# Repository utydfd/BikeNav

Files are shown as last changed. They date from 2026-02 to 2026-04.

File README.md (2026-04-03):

# BikeNav
An GPS navigation(originally intended for biking) with an E-ink screen, ESP32-S3 MCU and an SD card.
This repository contains code for the Arduino project and an Android app, as well as a PCB designed in KiCad and a case designed in Fusion 360.

## Map format
It uses standard raster 256x256px map tiles, right now from OSM, but can be changed to others.
The tiles are saved on the SD card in a ```ZOOM_LEVEL/X/Y.tile``` folder structure as 1 bit bitmap images.

## Data flow

Either import a GPX track or plan right inside the app(right now using project OSRM API), it downloads the required map tiles and saves them.

I can pick a trip from the main screen and send it over to the ESP via BLE, first the GPX is sent and then the tiles. They are converted from PNG to bitmap, compressed using RLE for faster transfers. The ESP is saving them to the SD card as they come. It’s also appending an index of tiles, which is sent from the ESP to the app, so that only the missing tiles are sent.

## ESPs software

The home screen contains smartphone like icons to "apps". The main one is obviously the map, which by default shows the current location. Pressing options brings up list of saved trips, clicking on it shows the preview and i can also start the navigation.

When navigating, the map rotates based on the upcoming GPX track; it shows the next turn distance and turn arrow(just calculated based on the angle of the turn). There are also screens for the progress and elevation graph. The GPX is loaded into PSRAM *(512kb allocated)* and PSRAM is also used for caching the map tiles *(~6MB allocated)*.

Other apps include the speedometer, phone(which has music controls along with battery %), weather(phone fetches from an API the forecast and also rain radar images), tracker(for recording GPX tracks), info(was used for debugging, has GPS, SD and battery statuses) and also mines and snake games. Those are not ideal but playable on the E-ink.

## Hardware

Its on a custom PCB, a standard 2 layer one. There are 2 regulators, one powering the ESP and other parts and the other solely for powering the front light - it has the EN pin connected to a GPIO so its controlled in software. The GPS module is connected via UART and also has an EN pin controllable. Micro SD card and the display are connected via SPI to the ESP. There is a TP4056 chip for charging, without the LEDs - its connected to the ESP so it can know the charging status.

For control, there is a rotary encoder(with a button) and 4 more buttons. The battery voltage is monitored with the ESP.

## BOM
- [Display](https://www.aliexpress.com/item/1005005183232092.html)
- [GP-02 GPS module](https://www.aliexpress.com/item/1005008117586848.html)
- [ESP32-S3 wroom module](https://www.aliexpress.com/item/1005004639132852.html)
- [SPX3819M5 LDO 3V3 regulator](https://www.aliexpress.com/item/1005004418830711.html)
- [2.2uF ceramic capacitors](https://www.aliexpress.com/item/1005002769519482.html)
- [15mm rotary endoder](https://www.aliexpress.com/item/1631706397.html)
- [USB-C breakout module](https://www.aliexpress.com/item/1005008296556115.html)

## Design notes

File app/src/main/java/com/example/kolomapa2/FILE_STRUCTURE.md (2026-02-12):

# KoloMapa2 - File Structure

Android companion app for ESP32S3 bicycle navigation device. This app downloads GPX routes, processes map tiles, and sends data to the ESP device via Bluetooth LE.

## Root Level

### `MainActivity.kt`
Main Android activity entry point. Handles incoming GPX file intents from file managers or share actions. Sets up Compose UI and delegates to MainScreen.

### `MainViewModel.kt`
Central ViewModel coordinating all app logic. Manages:
- Trip import/deletion
- Map tile downloading with progress tracking
- BLE connection to ESP32S3
- Data transfer (trips and tiles) to device
- UI state (loading, errors, storage stats)

## Models (`models/`)

### `Trip.kt`
Simple data class combining trip metadata and GPX content string.

### `TripMetadata.kt`
Serializable trip information including:
- Name, distance, elevation gain/loss
- Point count and bounding box
- Route description with origin/destination parsing
- Timestamp

## UI (`ui/`)

### `MainScreen.kt`
Main Compose UI with:
- Trip list display with cards
- BLE connection status indicator
- Import GPX file picker
- Trip details dialog
- Storage statistics
- Transfer progress indicators
- Permission requests (Bluetooth, location, storage)

### Theme files (`ui/theme/`)
- `Color.kt` - Material Design color palette
- `Theme.kt` - App theme configuration
- `Type.kt` - Typography definitions

## Utils (`utils/`)

### `BleManager.kt`
Bluetooth LE communication with ESP32S3:
- Device scanning and connection management
- Custom service UUID: 12345678-1234-1234-1234-123456789abc
- Tile transfer with RLE compression (16KB ESP limit)
- Tile inventory sync to skip tiles already on device
- Trip data transfer (GPX + metadata JSON)
- MTU negotiation (517 bytes) and chunked transfers (500 byte chunks)
- Flow control with write completion flags

### `GpxParser.kt`
Parses GPX XML files to extract:
- Track points (lat/lon/elevation)
- Trip names from metadata and track elements
- Route descriptions with origin→destination parsing
- Statistics: distance (Haversine formula), elevation changes
- Bounding box calculation

### `RleCompression.kt`
Run-Length Encoding compression for map tiles:
- Optimized for 1-bit bitmaps with large uniform areas
- Format: [count][value] pairs with 2-byte size header
- Compression ratio calculation
- Encode/decode with validation

### `StorageManager.kt`
File system operations in external storage (`/KoloMapa2/`):
- Trips: Save/load GPX files and metadata JSON
- Map tiles: Store preprocessed 1-bit bitmaps (zoom/x/y.bin)
- Storage statistics (total size, counts)
- Tile existence checking

### `TileDownloader.kt`
Downloads map tiles from OpenStreetMap tile servers:
- Uses keyless public raster tiles (`z/x/y.png`)
- Downloads zoom levels 9-18 with 2-tile padding
- Caching: skips already downloaded tiles
- Automatic preprocessing to 1-bit format
- Progress callbacks

### `TilePreprocessor.kt`
Converts PNG map tiles to 1-bit bitmaps (matches ESP32S3 processing):
- Floyd-Steinberg dithering with error diffusion
- Image processing: gamma correction (2.50), contrast (1.3), threshold (128)
- Output: 8KB per tile (256x256 pixels, 8 pixels per byte)
- Tile coordinate calculation (lat/lon → tile x/y)
- MUST match Arduino preprocessing exactly for consistency

## Data Flow

1. User imports GPX → `GpxParser` extracts route → `StorageManager` saves
2. `TileDownloader` fetches tiles for route bounding box
3. `TilePreprocessor` converts PNG → 1-bit bitmap → `StorageManager` saves
4. User sends to ESP → `BleManager` requests tile inventory, transfers trip + missing tiles via BLE
5. ESP32S3 receives and displays on e-paper screen

## Key Design Decisions

- External storage for persistence across reinstalls
- Exact preprocessing match with Arduino for consistent map rendering
- RLE compression for efficient BLE transfer (ESP has 16KB tile limit)
- Chunked transfers with flow control for reliability
- Offline-first: all data cached locally before transfer

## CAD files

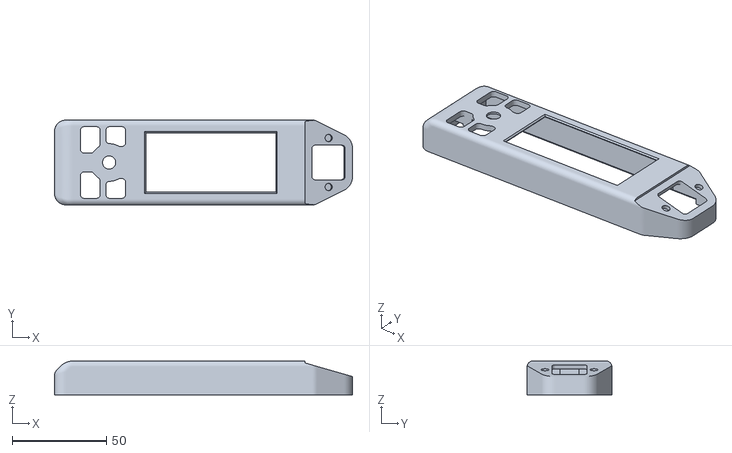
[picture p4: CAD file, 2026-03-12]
Case/top.stl
158.1 x 45.0 x 18.0

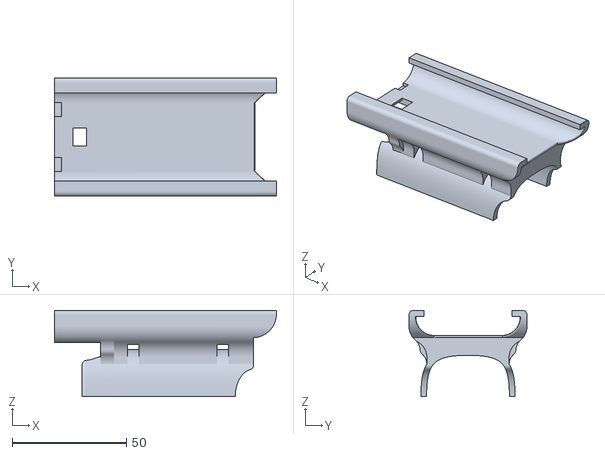
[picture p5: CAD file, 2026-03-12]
Case/mount.stl
97.0 x 51.6 x 37.8

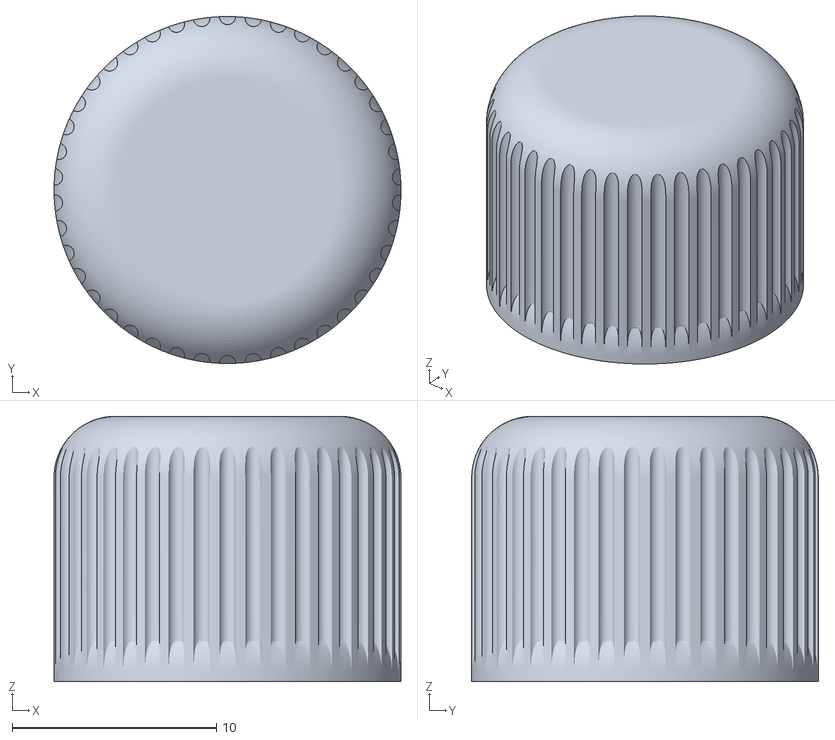
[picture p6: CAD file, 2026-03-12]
Case/knob.stl
17.0 x 17.0 x 13.0

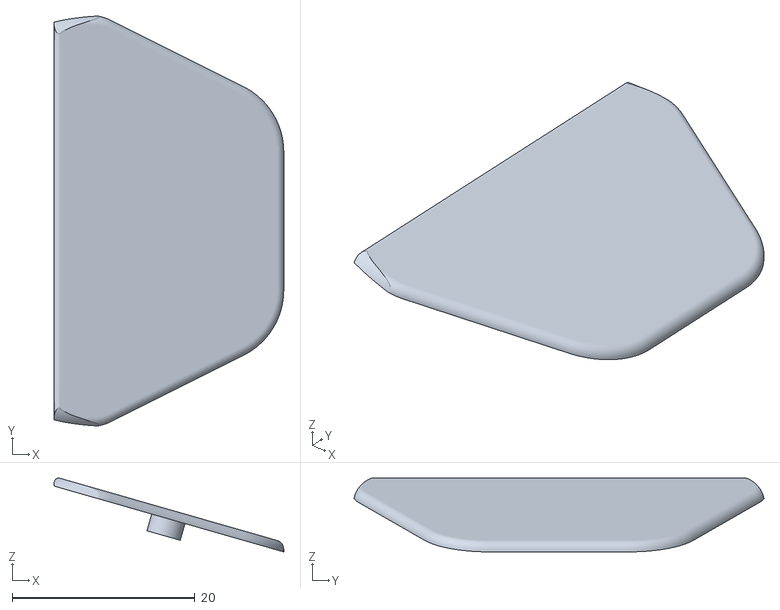
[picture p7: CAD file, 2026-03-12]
Case/cover.stl
25.1 x 44.9 x 8.08

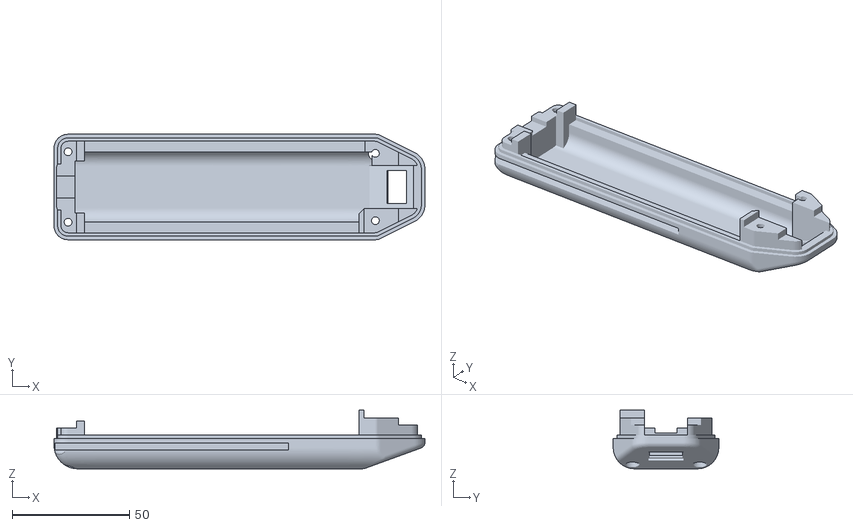
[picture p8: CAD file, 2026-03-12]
Case/bottom.stl
158.1 x 45.0 x 25.0

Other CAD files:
Case/KoloMapa2.f3d

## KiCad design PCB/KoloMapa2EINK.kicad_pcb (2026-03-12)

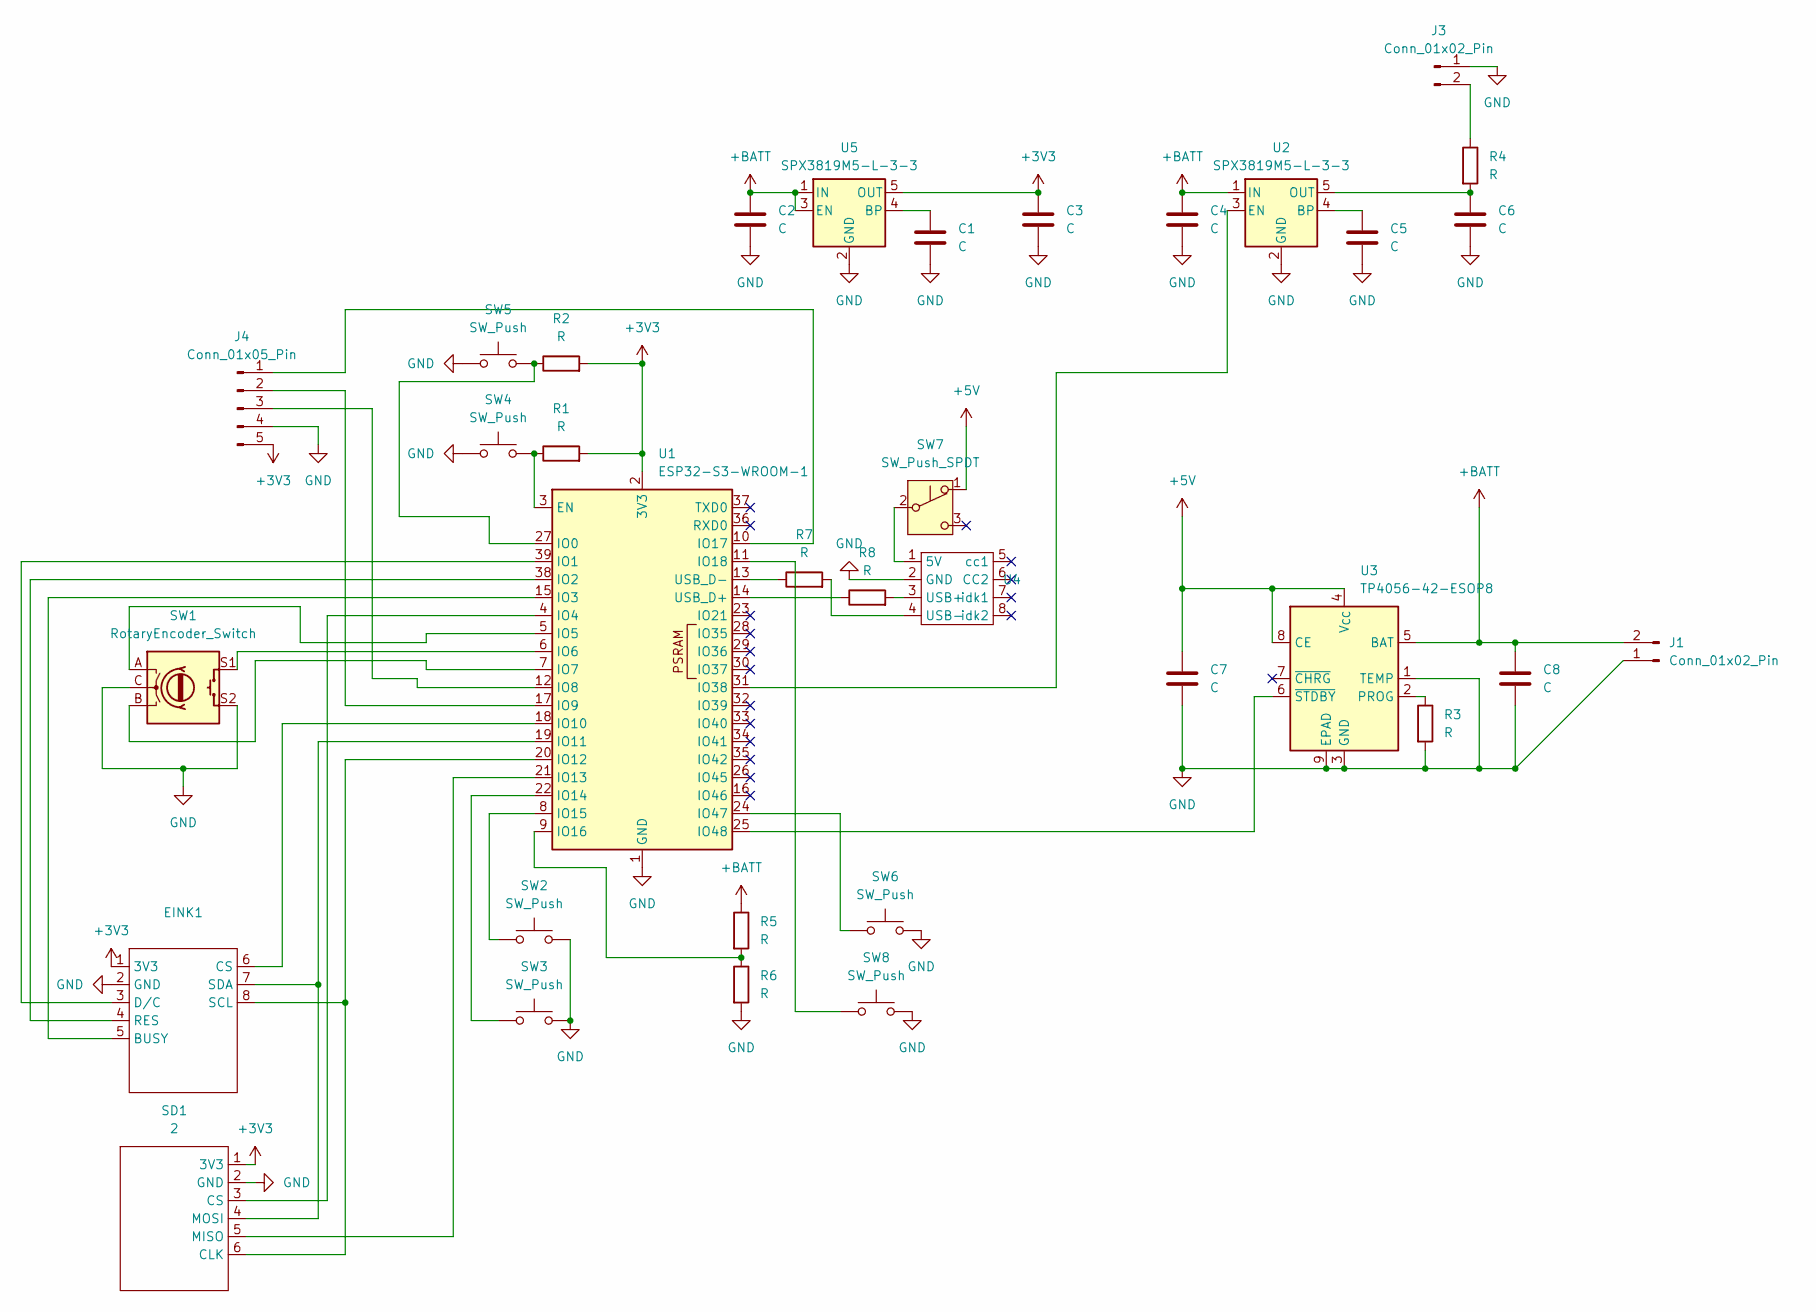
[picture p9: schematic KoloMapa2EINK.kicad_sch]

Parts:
C1, C2, C3, C4, C5, C6: C; C_1206_3216Metric_Pad1.33x1.80mm_HandSolder
C7: C; C_0402_1005Metric
C8: C; C_0504_1310Metric
EINK1: EINK
J1, J3: Conn_01x02_Pin; PinHeader_1x02_P2.54mm_Vertical
J4: Conn_01x05_Pin; PinHeader_1x05_P2.00mm_Vertical
R1, R2, R4, R5, R6: R; R_Axial_DIN0207_L6.3mm_D2.5mm_P10.16mm_Horizontal
R3: R; R_0402_1005Metric
R7, R8: R; R_Axial_DIN0207_L6.3mm_D2.5mm_P2.54mm_Vertical
SD1: 2; SD
SW1: RotaryEncoder_Switch; RotaryEncoder_Alps_EC11E-Switch_Vertical_H20mm
SW2, SW3, SW4, SW5, SW6, SW8: SW_Push; SW_PUSH_6mm
SW7: SW_Push_SPDT; SW_Slide_SPDT_Straight_CK_OS102011MS2Q
U1: ESP32-S3-WROOM-1
U2, U5: SPX3819M5-L-3-3; SOT-23-5
U3: TP4056-42-ESOP8; SOIC-8-1EP_3.9x4.9mm_P1.27mm_EP2.41x3.3mm_ThermalVias
U4: Untitled

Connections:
+3V3: C3.1, EINK1.1 (3V3), J4.5, R1.2, R2.2, SD1.1 (3V3), U1.2 (3V3), U5.5 (OUT)
+5V: C7.1, SW7.1 (A), U3.4 (V_{CC}), U3.8 (CE)
+BATT: C2.1, C4.1, C8.1, J1.2, R5.1, U2.1 (IN), U3.5 (BAT), U5.1 (IN), U5.3 (EN)
GND: C1.2, C2.2, C3.2, C4.2, C5.2, C6.2, C7.2, C8.2, EINK1.2 (GND), J1.1, J3.1, J4.4, R3.2, R6.2, SD1.2 (GND), SW1.C, SW1.S2, SW2.2, SW3.2, SW4.1, SW5.1, SW6.2, SW8.2, U1.1 (GND), U1.40 (GND), U1.41 (GND), U2.2 (GND), U3.1 (TEMP), U3.3 (GND), U3.9 (EPAD), U4.2 (GND), U5.2 (GND)
unnamed: EINK1.5 (BUSY), U1.15 (IO3)
unnamed: EINK1.6 (CS), U1.18 (IO10)
unnamed: EINK1.3 (D/C), U1.39 (IO1)
unnamed: EINK1.4 (RES), U1.38 (IO2)
unnamed: EINK1.8 (SCL), SD1.6 (CLK), U1.20 (IO12)
unnamed: EINK1.7 (SDA), SD1.4 (MOSI), U1.19 (IO11)
unnamed: J3.2, R4.1
unnamed: J4.1, U1.10 (IO17)
unnamed: J4.2, U1.17 (IO9)
unnamed: J4.3, U1.12 (IO8)
unnamed: SD1.3 (CS), U1.4 (IO4)
unnamed: SD1.5 (MISO), U1.21 (IO13)
unnamed: SW7.2 (B), U4.1 (5V)
unnamed: R1.1, SW4.2, U1.3 (EN)
unnamed: R2.1, SW5.2, U1.27 (IO0)
unnamed: SW1.A, U1.5 (IO5)
unnamed: SW1.S1, U1.6 (IO6)
unnamed: SW1.B, U1.7 (IO7)
unnamed: SW3.1, U1.22 (IO14)
unnamed: SW2.1, U1.8 (IO15)
unnamed: R5.2, R6.1, U1.9 (IO16)
unnamed: SW8.1, U1.11 (IO18)
unnamed: U1.31 (IO38), U2.3 (EN)
unnamed: SW6.1, U1.24 (IO47)
unnamed: U1.25 (IO48), U3.6 (~STDBY)
unnamed: R8.1, U1.14 (USB_D+)
unnamed: R7.1, U1.13 (USB_D-)
unnamed: C5.1, U2.4 (BP)
unnamed: C6.1, R4.2, U2.5 (OUT)
unnamed: R3.1, U3.2 (PROG)
unnamed: R8.2, U4.3 (USB+)
unnamed: R7.2, U4.4 (USB-)
unnamed: C1.1, U5.4 (BP)

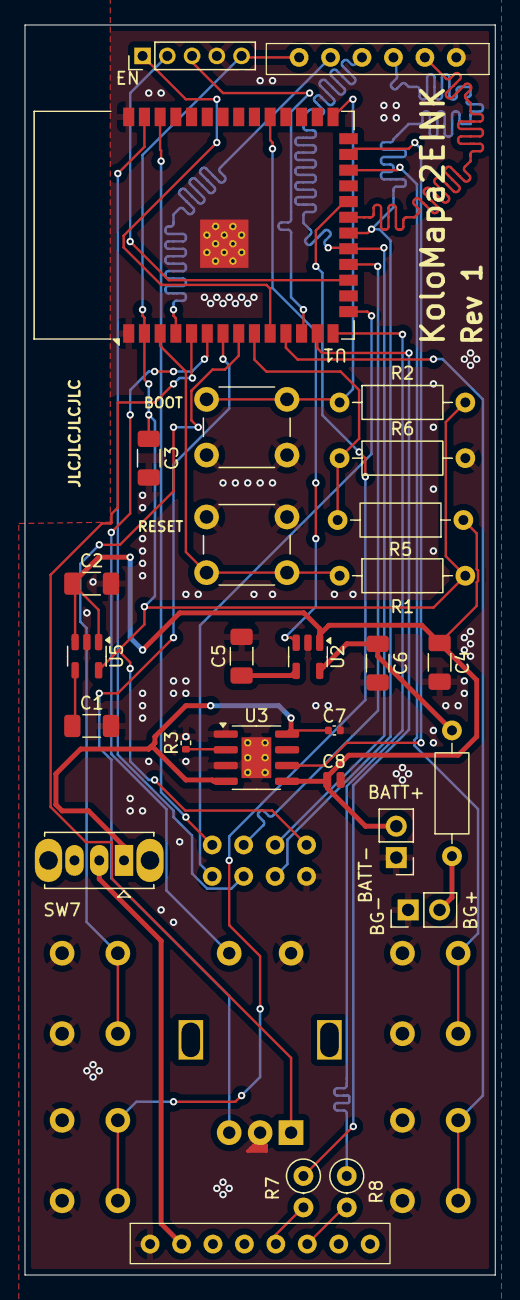
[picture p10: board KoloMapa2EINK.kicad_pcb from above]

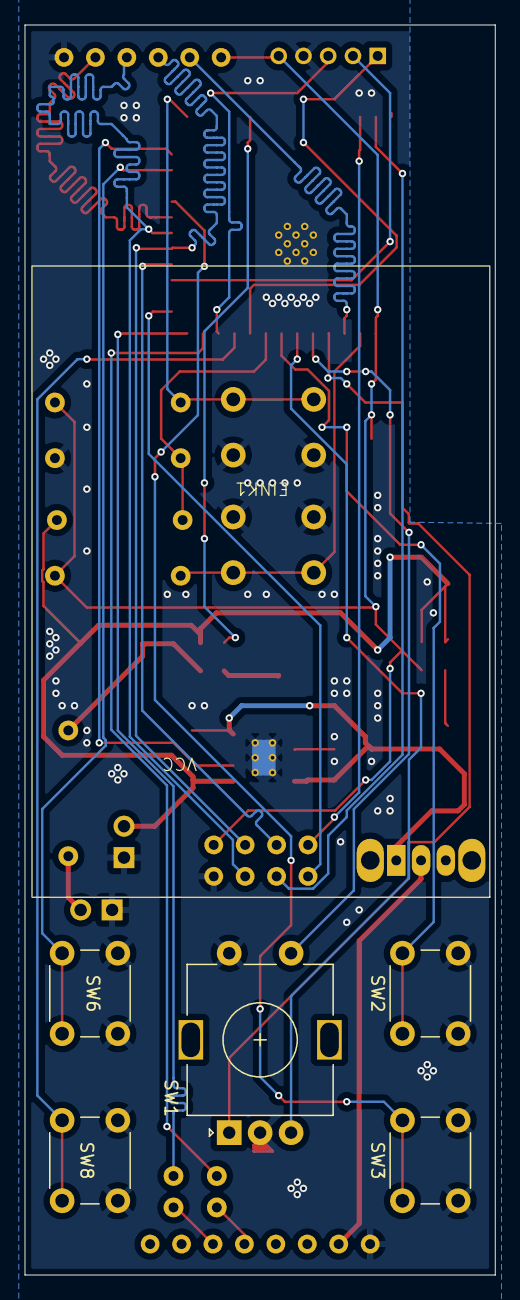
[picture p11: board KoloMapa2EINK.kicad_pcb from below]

Board: 2 copper layers, 38.0 x 101.0 mm, 34 parts (6 on the bottom side), 37 nets.

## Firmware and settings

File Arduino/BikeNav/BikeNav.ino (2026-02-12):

#include <GxEPD2_BW.h>
#include <U8g2_for_Adafruit_GFX.h>
#include <HardwareSerial.h>
#include <TinyGPS++.h>
#include <SPI.h>
#include <SD.h>
#include <time.h>
#include <sys/time.h>

// --- PAGE MANAGEMENT ENUM (must be before page includes) ---
enum PageType {
  PAGE_MAIN_MENU,
  PAGE_MAP,
  PAGE_SPEEDOMETER,
  PAGE_PHONE_APP,
  PAGE_WEATHER,
  PAGE_GAMES,
  PAGE_INFO,
  PAGE_SHUTDOWN,
  PAGE_SETTINGS,
  PAGE_TRACKER,
  PAGE_RECORDING,
  PAGE_RECORDING_OPTIONS,
  PAGE_WEATHER_OPTIONS,
  PAGE_SNAKE
};

// Forward declaration of navigateToPage (needed by page headers)
void navigateToPage(PageType page);

// Include all page headers
#include "timezone.h"
#include "bitmaps.h"
#include "tile_cache.h"
#include "ble_handler.h"
#include "battery_manager.h"
#include "notification_system.h"
#include "power_manager.h"
#include "status_bar.h"
#include "page_main_menu.h"
#include "page_map.h"
#include "page_speedometer.h"
#include "page_phone_app.h"
#include "page_weather.h"
#include "page_radar.h"
#include "page_weather_options.h"
#include "page_games.h"
#include "page_snake.h"
#include "page_info.h"
#include "page_settings.h"
#include "page_tracker.h"
#include "page_recording.h"
#include "page_recording_options.h"

// --- E-PAPER DISPLAY CONFIGURATION ---
#define EPD_CS_PIN 10
#define EPD_DC_PIN 1
#define EPD_RES_PIN 2
#define EPD_BUSY_PIN 3

// --- SD CARD CONFIGURATION ---
#define SD_CS_PIN 4

GxEPD2_BW<GxEPD2_290_BS, GxEPD2_290_BS::HEIGHT> display(GxEPD2_290_BS(EPD_CS_PIN, EPD_DC_PIN, EPD_RES_PIN, EPD_BUSY_PIN));
U8G2_FOR_ADAFRUIT_GFX u8g2_display;

// --- BATTERY MANAGER ---
BatteryManager batteryManager;

// --- GPS CONFIGURATION ---
#define RX1_PIN 8
#define TX1_PIN 9
HardwareSerial GPS_Serial(1);
TinyGPSPlus gps;

// --- TIMEZONE CONFIGURATION ---
// GPS returns UTC time. Automatic DST adjustment for Czech Republic.
// Winter (CET): UTC+1, Summer (CEST): UTC+2
// DST period: Last Sunday of March 2:00 AM to Last Sunday of October 3:00 AM

// Helper function to find the last Sunday of a given month and year
int getLastSundayOfMonth(int year, int month) {
  // Days in month
  const int daysInMonth[] = {31, 28, 31, 30, 31, 30, 31, 31, 30, 31, 30, 31};
  bool isLeapYear = (year % 4 == 0 && year % 100 != 0) || (year % 400 == 0);
  int lastDay = daysInMonth[month - 1];
  if (month == 2 && isLeapYear) {
    lastDay = 29;
  }

  // Calculate day of week for the last day of the month
  // Using Zeller's algorithm
  int q = lastDay;
  int m = month;
  int y = year;

  // Zeller's algorithm: for January and February, count them as months 13 and 14 of the previous year
  if (m < 3) {
    m += 12;
    y--;
  }

  int h = (q + (13 * (m + 1)) / 5 + y + y / 4 - y / 100 + y / 400) % 7;
  // h: 0=Saturday, 1=Sunday, 2=Monday, ..., 6=Friday

  // Find how many days to go back to reach Sunday (h=1)
  int daysBack = (h + 6) % 7;  // Days to go back from last day to last Sunday

  return lastDay - daysBack;
}

// Check if DST is active for Czech Republic
// DST: Last Sunday of March 2:00 UTC to Last Sunday of October 3:00 UTC
bool isDSTActive(int year, int month, int day, int hour) {
  int marchLastSunday = getLastSundayOfMonth(year, 3);
  int octoberLastSunday = getLastSundayOfMonth(year, 10);

  // Before March or after October -> winter time
  if (month < 3 || month > 10) {
    return false;
  }

  // April to September -> summer time
  if (month > 3 && month < 10) {
    return true;
  }

  // March: check if we're past the last Sunday at 2:00 AM
  if (month == 3) {
    if (day < marchLastSunday) {
      return false;
    } else if (day == marchLastSunday) {
      return hour >= 2;  // DST starts at 2:00 AM UTC
    } else {
      return true;
    }
  }

  // October: check if we're before the last Sunday at 3:00 AM
  if (month == 10) {
    if (day < octoberLastSunday) {
      return true;
    } else if (day == octoberLastSunday) {
      return hour < 3;  // DST ends at 3:00 AM UTC
    } else {
      return false;
    }
  }

  return false;
}

// Get timezone offset based on DST status
int getTimezoneOffset(int year, int month, int day, int hour) {
  return isDSTActive(year, month, day, hour) ? 2 : 1;  // +2 for summer, +1 for winter
}

// Convert GPS UTC time to local time with automatic DST adjustment
LocalTime getLocalTime() {
  LocalTime localTime;

  if (!gps.time.isValid() || !gps.date.isValid()) {
    // Return zeros if GPS time not available
    localTime.hour = 0;
    localTime.minute = 0;
    localTime.second = 0;
    localTime.day = 0;
    localTime.month = 0;
    localTime.year = 0;
    return localTime;
  }

  // Start with GPS UTC time
  localTime.hour = gps.time.hour();
  localTime.minute = gps.time.minute();
  localTime.second = gps.time.second();
  localTime.day = gps.date.day();
  localTime.month = gps.date.month();
  localTime.year = gps.date.year();

  // Calculate timezone offset based on UTC date/time for automatic DST
  int timezoneOffset = getTimezoneOffset(localTime.year, localTime.month, localTime.day, localTime.hour);
  localTime.hour += timezoneOffset;

  // Handle hour overflow (next day)
  if (localTime.hour >= 24) {
    localTime.hour -= 24;
    localTime.day++;

    // Days in month lookup (non-leap year, February handled separately)
    const int daysInMonth[] = {31, 28, 31, 30, 31, 30, 31, 31, 30, 31, 30, 31};

    // Check for leap year for February
    bool isLeapYear = (localTime.year % 4 == 0 && localTime.year % 100 != 0) || (localTime.year % 400 == 0);
    int maxDays = daysInMonth[localTime.month - 1];
    if (localTime.month == 2 && isLeapYear) {
      maxDays = 29;
    }

    // Handle day overflow (next month)
    if (localTime.day > maxDays) {
      localTime.day = 1;
      localTime.month++;

      // Handle month overflow (next year)
      if (localTime.month > 12) {
        localTime.month = 1;
        localTime.year++;
      }
    }
  }
  // Handle hour underflow (previous day)
  else if (localTime.hour < 0) {
    localTime.hour += 24;
    localTime.day--;

    // Handle day underflow (previous month)
    if (localTime.day < 1) {
      localTime.month--;

      // Handle month underflow (previous year)
      if (localTime.month < 1) {
        localTime.month = 12;
        localTime.year--;
      }

      // Set to last day of previous month
      const int daysInMonth[] = {31, 28, 31, 30, 31, 30, 31, 31, 30, 31, 30, 31};
      bool isLeapYear = (localTime.year % 4 == 0 && localTime.year % 100 != 0) || (localTime.year % 400 == 0);
      localTime.day = daysInMonth[localTime.month - 1];
      if (localTime.month == 2 && isLeapYear) {
        localTime.day = 29;
      }
    }
  }

  return localTime;
}

// --- INPUT PINS ---
#define CLK_PIN 5
#define DT_PIN  7
#define SW_PIN  6       // Rotary encoder button
#define BACK_PIN 47     // Back button
#define NEXT_PAGE_PIN 14 // Next page button
#define SETTINGS_PIN 15 // Settings button
#define OPTIONS_PIN 18  // Options button
#define BUTTON_DEBOUNCE 100  // Debounce time for faster mode changes
const unsigned long OPTIONS_RELEASE_DEBOUNCE = 60;

// --- GPS STATE ---
// Default if no GPS signal
double currentLat = 50.102382;
double currentLon = 14.392353;

bool gpsValid = false;
unsigned long lastGPSUpdate = 0;

// --- SD CARD STATE ---
bool sdCardPresent = false;
uint64_t sdCardSize = 0;  // Size in MB

// --- TRIP/NAVIGATION STATE ---
bool navigationActive = false;
bool tripRecording = false;

// --- DISPLAY DIMENSIONS ---
const int DISPLAY_WIDTH = 128;
const int DISPLAY_HEIGHT = 296;

// --- PAGE MANAGEMENT VARIABLES ---
PageType currentPage = PAGE_MAIN_MENU;
PageType previousPage = PAGE_MAIN_MENU;
bool settingsOpen = false;
bool skipPageInit = false;  // Skip page initialization when returning from settings
unsigned long lastPageNavigation = 0;  // Timestamp of last page change
const unsigned long PAGE_NAV_COOLDOWN = 300;  // Cooldown period after page navigation (ms)

// --- SETTINGS PANEL STATE ---
// Note: SettingsPanelState enum is defined in page_settings.h
SettingsPanelState settingsPanelState = SETTINGS_CLOSED;

// --- HARDWARE CONTROL STATE ---
bool backlightEnabled = false;   // Backlight (pin 38) - default OFF
bool gpsEnabled = true;          // GPS power (pin 17) - default ON
bool bluetoothEnabled = true;    // Bluetooth - default ON

// Forward declarations (navigateToPage already declared above before includes)
void handleBack();
void handleSettings();
void handleNextPage();
bool handleSpeedometerBack();
void handleSpeedometerOptions();
bool handleMapBack();
bool handleInfoBack();

// External from page_main_menu.h
extern int selectedPageId;

// --- INPUT STATE ---
volatile bool encoderChanged = false;
volatile int encoderDelta = 0;
volatile bool buttonPressed = false;
volatile bool backPressed = false;
volatile bool nextPagePressed = false;
volatile bool settingsPressed = false;
volatile bool optionsPressed = false;
volatile bool chargingStateChanged = false;
volatile unsigned long lastButtonTime = 0;
volatile unsigned long lastBackTime = 0;
volatile unsigned long lastNextPageTime = 0;
volatile unsigned long lastSettingsTime = 0;
volatile unsigned long lastOptionsTime = 0;
volatile unsigned long lastOptionsReleaseTime = 0;
volatile unsigned long lastChargingTime = 0;

// Button state tracking (prevents double-press when holding button)
volatile bool waitingForButtonRelease = false;  // True after processing encoder press, waiting for physical release
volatile bool waitingForOptionsRelease = false; // True after processing options press, waiting for physical release

// --- INTERRUPT SERVICE ROUTINES ---
/* Rotary encoder interrupt routine based on Oleg Mazurov's code
 * https://chome.nerpa.tech/mcu/rotary-encoder-interrupt-service-routine-for-avr-micros/
 * Updates encoderDelta when encoder has rotated a full detent (4 steps)
 */
void IRAM_ATTR encoderISR() {
  static uint8_t old_AB = 3;  // Lookup table index
  static int8_t encval = 0;   // Encoder value
  static const int8_t enc_states[] = {0,-1,1,0,1,0,0,-1,-1,0,0,1,0,1,-1,0}; // Lookup table

  old_AB <<= 2;  // Remember previous state

  if (digitalRead(CLK_PIN)) old_AB |= 0x02;  // Add current state of pin A (CLK)
  if (digitalRead(DT_PIN)) old_AB |= 0x01;   // Add current state of pin B (DT)

  encval += enc_states[(old_AB & 0x0f)];

  // Update counter if encoder has rotated a full indent, that is at least 4 steps
  if (encval > 3) {        // Four steps forward
    encoderDelta += 1;     // ACCUMULATE instead of overwrite - allows fast rotation
    encoderChanged = true;
    encval = 0;
  }
  else if (encval < -3) {  // Four steps backward
    encoderDelta += -1;    // ACCUMULATE instead of overwrite - allows fast rotation
    encoderChanged = true;
    encval = 0;
  }
}

void IRAM_ATTR buttonISR() {
  unsigned long currentTime = millis();
  if (currentTime - lastButtonTime > BUTTON_DEBOUNCE) {
    if (digitalRead(SW_PIN) == LOW) {
      buttonPressed = true;
      lastButtonTime = currentTime;
    }
  }
}

void IRAM_ATTR backISR() {
  unsigned long currentTime = millis();
  if (currentTime - lastBackTime > BUTTON_DEBOUNCE) {
    if (digitalRead(BACK_PIN) == LOW) {
      backPressed = true;
      lastBackTime = currentTime;
    }
  }
}

void IRAM_ATTR nextPageISR() {
  unsigned long currentTime = millis();
  if (currentTime - lastNextPageTime > BUTTON_DEBOUNCE) {
    if (digitalRead(NEXT_PAGE_PIN) == LOW) {
      nextPagePressed = true;
      lastNextPageTime = currentTime;
    }
  }
}

void IRAM_ATTR settingsISR() {
  unsigned long currentTime = millis();
  if (currentTime - lastSettingsTime > BUTTON_DEBOUNCE) {
    if (digitalRead(SETTINGS_PIN) == LOW) {
      settingsPressed = true;
      lastSettingsTime = currentTime;
    }
  }
}

void IRAM_ATTR optionsISR() {
  unsigned long currentTime = millis();
  if (digitalRead(OPTIONS_PIN) == LOW) {
    if (!waitingForOptionsRelease && currentTime - lastOptionsTime > BUTTON_DEBOUNCE) {
      optionsPressed = true;
      lastOptionsTime = currentTime;
    }
  } else {
    lastOptionsReleaseTime = currentTime;
  }
}

void IRAM_ATTR chargingISR() {
  unsigned long currentTime = millis();
  // Debounce charging state changes (500ms to avoid noise)
  if (currentTime - lastChargingTime > 500) {
    chargingStateChanged = true;
    lastChargingTime = currentTime;
  }
}
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
void loop() {
  // Update BLE handler (for delayed trip list sending)
  updateBleHandler();

  // Handle pending page navigation from BLE (deferred to avoid display corruption)
  extern volatile bool pendingPageNavigation;
  extern volatile PageType pendingNavigationPage;
  if (pendingPageNavigation) {
    pendingPageNavigation = false;  // Clear flag immediately to avoid repeated navigation

    // Check if enough time has passed since last navigation (cooldown)
    unsigned long timeSinceLastNav = millis() - lastPageNavigation;
    if (timeSinceLastNav >= PAGE_NAV_COOLDOWN) {
      Serial.printf("Executing deferred navigation to page %d\n", pendingNavigationPage);
      navigateToPage(pendingNavigationPage);
    } else {
      // Still in cooldown - re-queue for next loop iteration
      Serial.printf("Navigation still in cooldown (%lu ms remaining), re-queuing\n",
                    PAGE_NAV_COOLDOWN - timeSinceLastNav);
      pendingPageNavigation = true;
    }
  }

  // Update battery manager (checks internally if update interval has elapsed)
  batteryManager.update();

  // Handle charging state change interrupt
  if (chargingStateChanged) {
    chargingStateChanged = false;  // Clear interrupt flag

    // Force battery manager to read current charging state
    batteryManager.forceUpdate();

    // Show notification
    bool isNowCharging = batteryManager.getIsCharging();

    if (isNowCharging) {
      // Charging started
      char percentStr[16];
      snprintf(percentStr, sizeof(percentStr), "%.0f%%", batteryManager.getPercentage());

      showNotification(
        "Battery",
        "Charging started",
        percentStr,
        ICON_INFO,
        5000  // Show for 5 seconds
      );

      Serial.println("Battery: Charging started");
    } else {
      // Charging stopped (finished or unplugged)
      char percentStr[16];
      snprintf(percentStr, sizeof(percentStr), "%.0f%%", batteryManager.getPercentage());

      char line2[32];
      if (batteryManager.getPercentage() >= 95.0f) {
        snprintf(line2, sizeof(line2), "%s - Full", percentStr);
      } else {
        snprintf(line2, sizeof(line2), "%s", percentStr);
      }

      showNotification(
        "Battery",
        "Charging stopped",
        line2,
        ICON_INFO,
        5000  // Show for 5 seconds
      );

      Serial.println("Battery: Charging stopped");
    }
  }

  // Read GPS data
  static bool timeSetFromGPS = false;
  while (GPS_Serial.available() > 0) {
    if (gps.encode(GPS_Serial.read())) {
      if (gps.location.isValid()) {
        currentLat = gps.location.lat();
        currentLon = gps.location.lng();
        if (!gpsValid) {
          Serial.println("GPS lock acquired!");
          Serial.printf("Location: %.6f, %.6f\n", currentLat, currentLon);
        }
        gpsValid = true;
        lastGPSUpdate = millis();

        // Check if GPS position changed and trigger screen update if needed
        // Works in both navigation mode and plain map mode
        checkGPSPositionChange();
      }

      // Set system time from GPS (once when GPS first locks)
      if (!timeSetFromGPS && gps.date.isValid() && gps.time.isValid()) {
        struct tm timeinfo;
        timeinfo.tm_year = gps.date.year() - 1900;  // Years since 1900
        timeinfo.tm_mon = gps.date.month() - 1;      // Months since January (0-11)
        timeinfo.tm_mday = gps.date.day();
        timeinfo.tm_hour = gps.time.hour();
        timeinfo.tm_min = gps.time.minute();
        timeinfo.tm_sec = gps.time.second();
        timeinfo.tm_isdst = -1;  // Auto-detect DST

        time_t utcTime = mktime(&timeinfo);

        // Apply timezone offset (CET/CEST for Czech Republic)
        int timezoneOffset = isDSTActive(gps.date.year(), gps.date.month(), gps.date.day(), gps.time.hour()) ? 2 : 1;
        time_t localTime = utcTime + (timezoneOffset * 3600);

        // Set the system time
        struct timeval tv = { .tv_sec = localTime, .tv_usec = 0 };
        settimeofday(&tv, NULL);

        timeSetFromGPS = true;
        Serial.printf("System time set from GPS: %04d-%02d-%02d %02d:%02d:%02d (UTC+%d)\n",
                     gps.date.year(), gps.date.month(), gps.date.day(),
                     gps.time.hour(), gps.time.minute(), gps.time.second(), timezoneOffset);
      }
    }
  }
  
  // Handle encoder rotation
  if (encoderChanged) {
    // Atomically capture and reset the accumulated delta value
    // This prevents race conditions and ensures we don't lose counts
    noInterrupts();
    int capturedDelta = encoderDelta;
    encoderDelta = 0;
    encoderChanged = false;
    interrupts();

    // Mark user activity to prevent status bar from auto-refreshing during scrolling
    markUserActivity();

    switch (currentPage) {
      case PAGE_MAIN_MENU:
        handleMainMenuEncoder(capturedDelta);
        break;
      case PAGE_MAP:
        handleMapEncoder(capturedDelta);
        break;
      case PAGE_SETTINGS:
        handleSettingsEncoder(capturedDelta);
        break;
      case PAGE_TRACKER:
        handleTrackerEncoder(capturedDelta);
        break;
      case PAGE_RECORDING:
        handleRecordingEncoder(capturedDelta);
        break;
      case PAGE_RECORDING_OPTIONS:
        handleRecordingOptionsEncoder(capturedDelta);
        break;
      case PAGE_INFO:
        handleInfoEncoder(capturedDelta);
        break;
      case PAGE_WEATHER:
        handleWeatherEncoder(capturedDelta);
        break;
      case PAGE_WEATHER_OPTIONS:
        handleWeatherOptionsEncoder(capturedDelta);
        break;
      case PAGE_GAMES:
        handleGamesEncoder(capturedDelta);
        break;
      case PAGE_SNAKE:
        handleSnakeEncoder(capturedDelta);
        break;
      case PAGE_PHONE_APP:
        handlePhoneAppEncoder(capturedDelta);
        break;
      // Add other page encoder handlers as needed
    }
  }
  
  // Check for long-press on encoder button to reset map view
  // ONLY on map page and map subpage (not trips list or other sub-pages)
  // Check this BEFORE normal button handling to prevent mode cycling during long press
  if (currentPage == PAGE_MAP && currentMapSubPage == MAP_SUBPAGE_MAP) {
    extern bool checkEncoderLongPress();
    extern void resetMapView();
    if (checkEncoderLongPress()) {
      // Long press detected - reset map view
      resetMapView();
    }
  } else if (currentPage == PAGE_RECORDING && isRecording) {
    extern bool checkEncoderLongPress();
    extern void resetRecordingView();
    if (checkEncoderLongPress()) {
      // Long press detected - reset recording view
      resetRecordingView();
    }
  }

  // Check if we're waiting for button release
  if (waitingForButtonRelease) {
    // Check if button has been physically released
    if (digitalRead(SW_PIN) == HIGH) {
      // Button released! Clear any pending presses and reset state
      waitingForButtonRelease = false;
      buttonPressed = false;  // Clear any ISR triggers that happened while holding
      Serial.println("Button released, ready for next press");
    } else {
      // Still holding button, clear any ISR triggers
      buttonPressed = false;
    }
  }

  // Check if we're waiting for options release
  if (waitingForOptionsRelease) {
    // Check if options button has been physically released
    if (digitalRead(OPTIONS_PIN) == HIGH) {
      if (millis() - lastOptionsReleaseTime >= OPTIONS_RELEASE_DEBOUNCE) {
        // Button released! Clear any pending presses and reset state
        waitingForOptionsRelease = false;
        optionsPressed = false;  // Clear any ISR triggers that happened while holding
        Serial.println("Options released, ready for next press");
      }
    } else {
      // Still holding button, clear any ISR triggers
      optionsPressed = false;
    }
  }

  // Handle encoder button press
  if (buttonPressed && !waitingForButtonRelease) {
    buttonPressed = false;
    markUserActivity();  // Mark user activity
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

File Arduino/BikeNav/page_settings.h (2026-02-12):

// page_settings.h
#ifndef PAGE_SETTINGS_H
#define PAGE_SETTINGS_H
#include <GxEPD2_BW.h>
#include <U8g2_for_Adafruit_GFX.h>
#include "notification_system.h"
#include "bitmaps.h"

extern GxEPD2_BW<GxEPD2_290_BS, GxEPD2_290_BS::HEIGHT> display;
extern U8G2_FOR_ADAFRUIT_GFX u8g2_display;
extern const int DISPLAY_WIDTH;
extern const int DISPLAY_HEIGHT;

// Forward declare SettingsPanelState enum (defined in BikeNav.ino)
enum SettingsPanelState {
  SETTINGS_CLOSED = 0,
  SETTINGS_NOTIFICATIONS = 1,
  SETTINGS_QUICK_SETTINGS = 2
};

// External references from BikeNav.ino
extern bool backlightEnabled;
extern bool gpsEnabled;
extern bool bluetoothEnabled;
extern SettingsPanelState settingsPanelState;

// External references for GPS and BLE
extern TinyGPSPlus gps;
extern BLEServer* pServer;
extern void startBLE();
extern void stopBLE();

// External references to battery manager
#include "battery_manager.h"

// External reference to LocalTime and getLocalTime from BikeNav.ino
extern LocalTime getLocalTime();

// --- NOTIFICATIONS PANEL STATE ---
int selectedNotificationIndex = 0;
int expandedNotificationIndex = -1;  // -1 = no notification expanded

// --- QUICK SETTINGS STATE ---
const int TILE_COUNT = 5;  // Added time/date tile
enum QuickSettingsTile {
  TILE_BLUETOOTH = 0,
  TILE_BACKLIGHT = 1,
  TILE_GPS = 2,
  TILE_BATTERY = 3,
  TILE_DATETIME = 4
};
int selectedTileIndex = 0;

// GPS confirmation dialog state
bool showingGPSDialog = false;

// BT confirmation dialog state
bool showingBTDialog = false;

// --- HELPER FUNCTIONS ---

// Get GPS acquisition stage - use the correct logic from page_info.h
// 0=no data, 1=has time, 2=has date, 3=has location
int getGPSStage() {
  // Check location first (fully locked)
  if (gps.location.isValid() && gps.satellites.value() > 0) {
    return 3;  // GPS_STAGE_LOCATION
  }

  // Check date - valid if year >= 2025 (not default 2000)
  bool dateAcquired = false;
  if (gps.date.isValid() && gps.date.year() >= 2025) {
    dateAcquired = true;
  }

  // Check time - valid if not default 00:00:00
  bool timeAcquired = false;
  if (gps.time.isValid()) {
    // Time is acquired if it's not all zeros
    if (!(gps.time.hour() == 0 && gps.time.minute() == 0 && gps.time.second() == 0)) {
      timeAcquired = true;
    }
  }

  // Return appropriate stage
  if (dateAcquired) {
    return 2;  // GPS_STAGE_DATE
  } else if (timeAcquired) {
    return 1;  // GPS_STAGE_TIME
  } else {
    return 0;  // GPS_STAGE_NO_DATA
  }
}

// Check if BLE is connected
bool isBLEConnected() {
  if (pServer == nullptr) {
    return false;
  }
  return pServer->getConnectedCount() > 0;
}

// External reference to drawSegmentedProgressBar from page_info.h
extern void drawSegmentedProgressBar(int x, int y, int width, int height, int segments, int filled);

// --- RENDER FUNCTIONS ---

// Render a single notification card
void renderNotificationCard(int y, Notification* notif, bool selected, bool expanded) {
  const int cardX = 2;
  const int cardWidth = DISPLAY_WIDTH - 4;
  const int cardHeight = expanded ? 100 : 50;  // 2x height when expanded

  if (selected) {
    // Selected: black background
    display.fillRect(cardX, y, cardWidth, cardHeight, GxEPD_BLACK);
    display.drawRect(cardX, y, cardWidth, cardHeight, GxEPD_WHITE);

    u8g2_display.setForegroundColor(GxEPD_WHITE);
    u8g2_display.setBackgroundColor(GxEPD_BLACK);
  } else {
    // Unselected: white background with border
    display.fillRect(cardX, y, cardWidth, cardHeight, GxEPD_WHITE);
    display.drawRect(cardX, y, cardWidth, cardHeight, GxEPD_BLACK);

    u8g2_display.setForegroundColor(GxEPD_BLACK);
    u8g2_display.setBackgroundColor(GxEPD_WHITE);
  }

  // Draw icon (39x39) - always in same position
  const int iconX = cardX + 4;
  const int iconY = y + 5;  // Fixed position from top, doesn't move when expanded
  const int iconBottomY = iconY + 39;  // Y position where icon ends

  if (notif->icon != nullptr) {
    if (selected) {
      display.drawBitmap(iconX, iconY, notif->icon, 39, 39, GxEPD_WHITE);
    } else {
      display.drawBitmap(iconX, iconY, notif->icon, 39, 39, GxEPD_BLACK);
    }
  }

  // Draw text
  const int textXRight = cardX + 47;  // Text starts to the right of icon
  const int textXFull = cardX + 4;    // Text starts from left edge (under icon)
  int textStartY = y + 16;

  u8g2_display.setFont(u8g2_font_helvB08_tf);
  u8g2_display.setCursor(textXRight, textStartY);
  u8g2_display.print(notif->heading);

  u8g2_display.setFont(u8g2_font_profont10_tf);

  if (expanded) {
    // Expanded view: Show full text with word wrapping
    // First 3 lines to the right of icon, then full width below
    const int maxCharsRight = 12;   // Chars per line next to icon
    const int maxCharsFull = 19;    // Chars per line below icon (full width)
    const int lineHeight = 11;
    const int linesNextToIcon = 3;  // Number of lines to render next to icon
    int currentY = textStartY + 12;
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

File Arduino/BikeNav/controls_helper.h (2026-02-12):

#ifndef CONTROLS_HELPER_H
#define CONTROLS_HELPER_H

#include <GxEPD2_BW.h>
#include <U8g2_for_Adafruit_GFX.h>
#include <math.h>
#include "bitmaps.h"

// External references from main program
extern GxEPD2_BW<GxEPD2_290_BS, GxEPD2_290_BS::HEIGHT> display;
extern U8G2_FOR_ADAFRUIT_GFX u8g2_display;
extern const int DISPLAY_WIDTH;
extern const int DISPLAY_HEIGHT;

// CONTROLS bitmap dimensions (from bitmaps.h)
const int CONTROLS_WIDTH = 107;
const int CONTROLS_HEIGHT = 60;

// Button label positions - these correspond to the 5 button areas in the bitmap
// The bitmap shows 4 rounded rectangles in corners plus center encoder
enum ControlButton {
  CONTROL_BACK = 0,           // Top-left button (back)
  CONTROL_SETTINGS = 1,       // Top-right button (settings)
  CONTROL_ENCODER = 2,        // Center button (encoder/OK)
  CONTROL_OPTIONS = 3,        // Bottom-left button (options)
  CONTROL_NEXT_PAGE = 4       // Bottom-right button (next page)
};

// Button configuration structure
struct ButtonLabel {
  ControlButton button;
  const char* label;
};

/**
 * Draw the controls bitmap with button labels
 * Places labels above or below their buttons (encoder rotation gets a pointer line + curved arrow)
 *
 * @param y Y position to draw the controls at (typically near bottom of screen)
 * @param labels Array of ButtonLabel structs defining which buttons have labels
 * @param labelCount Number of labels in the array
 * @param encoderPressLabel Label drawn inside the encoder circle (press action)
 */
void drawControlsWithLabels(int y, const ButtonLabel* labels, int labelCount,
                             const char* encoderPressLabel = nullptr) {
  // Calculate X position to center the bitmap
  int bitmapX = (DISPLAY_WIDTH - CONTROLS_WIDTH) / 2;

  // Setup text rendering first to measure text
  u8g2_display.setFontMode(1);
  u8g2_display.setForegroundColor(GxEPD_BLACK);
  u8g2_display.setBackgroundColor(GxEPD_WHITE);
  u8g2_display.setFont(u8g2_font_helvB08_tf);

  const int TEXT_HEIGHT = 10;  // Approximate text height for font
  const int TEXT_GAP = 2;      // Gap between bitmap edge and text
  const int ROW_GAP = 2;       // Gap between stacked text rows

  const int LEFT_CENTER_X = bitmapX + 20;
  const int RIGHT_CENTER_X = bitmapX + (CONTROLS_WIDTH - 20);
  const int CENTER_X = bitmapX + (CONTROLS_WIDTH / 2);
  const int CENTER_Y = y + (CONTROLS_HEIGHT / 2);
  const int ENCODER_RADIUS = 18;
  const int LINE_GAP = 8;
  const int TOP_LINE_GAP = 16;
  const int PRESS_TEXT_UP = 5;
  const int ARROW_RADIUS_OFFSET = 4;
  const int ARC_GAP = 2;
  const int TOP_ARC_GAP = 6;
  const int TOP_LINE_END_TRIM = 8;
  const int BOTTOM_LINE_END_PUSH = 4;
  const int ARROWHEAD_LEN = 6;
  const float ARROWHEAD_SPREAD = 0.55f;  // ~32 degrees
  const float ARC_SPAN = 0.90f;          // ~52 degrees

  const int TOP_BASELINE = y - TEXT_GAP;
  const int BOTTOM_BASELINE = y + CONTROLS_HEIGHT + TEXT_GAP + TEXT_HEIGHT;
  const int EXTRA_BOTTOM_BASELINE = BOTTOM_BASELINE + TEXT_HEIGHT + ROW_GAP;
  const int EXTRA_TOP_BASELINE = TOP_BASELINE - TEXT_HEIGHT - ROW_GAP;

  bool hasTopLabels = false;
  bool hasBottomLabels = false;
  for (int i = 0; i < labelCount; i++) {
    if (labels[i].button == CONTROL_BACK || labels[i].button == CONTROL_SETTINGS) {
      hasTopLabels = true;
    }
    if (labels[i].button == CONTROL_OPTIONS || labels[i].button == CONTROL_NEXT_PAGE) {
      hasBottomLabels = true;
    }
  }

  int encoderBaseline = BOTTOM_BASELINE;
  if (hasBottomLabels) {
    if (EXTRA_BOTTOM_BASELINE <= DISPLAY_HEIGHT) {
      encoderBaseline = EXTRA_BOTTOM_BASELINE;
    } else if (EXTRA_TOP_BASELINE - TEXT_HEIGHT >= 0) {
      encoderBaseline = EXTRA_TOP_BASELINE;
    }
  } else if (hasTopLabels) {
    encoderBaseline = BOTTOM_BASELINE;
  }

  auto drawThickLine = [&](int x1, int y1, int x2, int y2) {
    display.drawLine(x1, y1, x2, y2, GxEPD_BLACK);
    int dx = x2 - x1;
    int dy = y2 - y1;
    int offsetX = -dy;
    int offsetY = dx;
    if (abs(offsetX) >= abs(offsetY)) {
      offsetX = (offsetX >= 0) ? 1 : -1;
      offsetY = 0;
    } else {
      offsetX = 0;
      offsetY = (offsetY >= 0) ? 1 : -1;
    }

    int midX = (x1 + x2) / 2;
    int midY = (y1 + y2) / 2;
    int radialX = midX - CENTER_X;
    int radialY = midY - CENTER_Y;
    if ((offsetX * radialX + offsetY * radialY) < 0) {
      offsetX = -offsetX;
      offsetY = -offsetY;
    }

    display.drawLine(x1 + offsetX, y1 + offsetY, x2 + offsetX, y2 + offsetY, GxEPD_BLACK);
  };

  auto drawArc = [&](int centerX, int centerY, int radius, float startAngle, float endAngle) {
    const int steps = 10;
    float step = (endAngle - startAngle) / steps;
    float prevX = centerX + cosf(startAngle) * radius;
    float prevY = centerY + sinf(startAngle) * radius;

    for (int i = 1; i <= steps; i++) {
      float angle = startAngle + (step * i);
      float nextX = centerX + cosf(angle) * radius;
      float nextY = centerY + sinf(angle) * radius;
      drawThickLine((int)lroundf(prevX), (int)lroundf(prevY), (int)lroundf(nextX), (int)lroundf(nextY));
      prevX = nextX;
      prevY = nextY;
    }
  };

  auto drawArrowhead = [&](int tipX, int tipY, float directionAngle, int length, float spread) {
    float leftAngle = directionAngle + spread;
    float rightAngle = directionAngle - spread;
    int leftX = (int)lroundf(tipX - (cosf(leftAngle) * length));
    int leftY = (int)lroundf(tipY - (sinf(leftAngle) * length));
    int rightX = (int)lroundf(tipX - (cosf(rightAngle) * length));
    int rightY = (int)lroundf(tipY - (sinf(rightAngle) * length));
    drawThickLine(tipX, tipY, leftX, leftY);
    drawThickLine(tipX, tipY, rightX, rightY);
  };

  // Draw the CONTROLS bitmap first
  display.drawBitmap(bitmapX, y, CONTROLS, CONTROLS_WIDTH, CONTROLS_HEIGHT, GxEPD_BLACK);

  // Draw encoder press label inside the circle
  if (encoderPressLabel && encoderPressLabel[0] != '\0') {
    int pressWidth = u8g2_display.getUTF8Width(encoderPressLabel);
    int pressX = CENTER_X - (pressWidth / 2);
    int pressBaseline = CENTER_Y + (TEXT_HEIGHT / 2) - 1 - PRESS_TEXT_UP;

    if (pressX < 0) {
      pressX = 0;
    }
    int maxPressX = DISPLAY_WIDTH - pressWidth;
    if (pressX > maxPressX) {
      pressX = maxPressX;
    }
    if (pressBaseline < TEXT_HEIGHT) {
      pressBaseline = TEXT_HEIGHT;
    }
    if (pressBaseline > DISPLAY_HEIGHT) {
      pressBaseline = DISPLAY_HEIGHT;
    }

    u8g2_display.setCursor(pressX, pressBaseline);
    u8g2_display.print(encoderPressLabel);
  }
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

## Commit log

2026-02-12 Update README to clarify repository contents
    Removed mention of STL files and PCB design from the repository description.
2026-03-10 Enhance README with detailed project information
    Expanded the README to include details about data flow, ESP software, hardware specifications, and bill of materials.
2026-03-12 Update README to clarify project components
    Expanded repository description to include PCB and case designs.
2026-04-03 Update BOM with new components and links
